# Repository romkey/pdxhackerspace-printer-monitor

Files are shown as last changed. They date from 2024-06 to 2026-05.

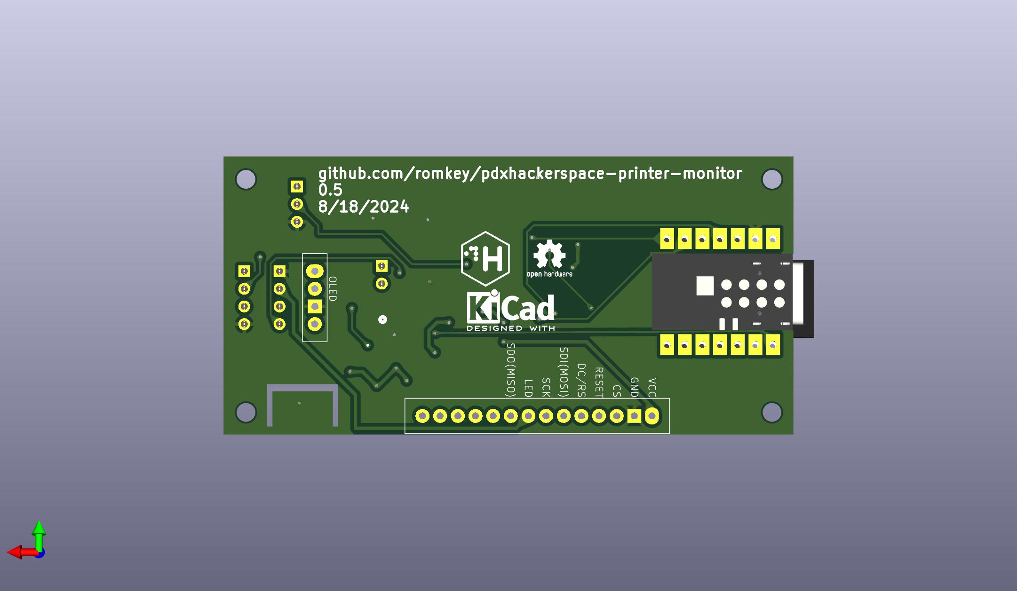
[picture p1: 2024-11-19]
hardware/0.5/back.jpg

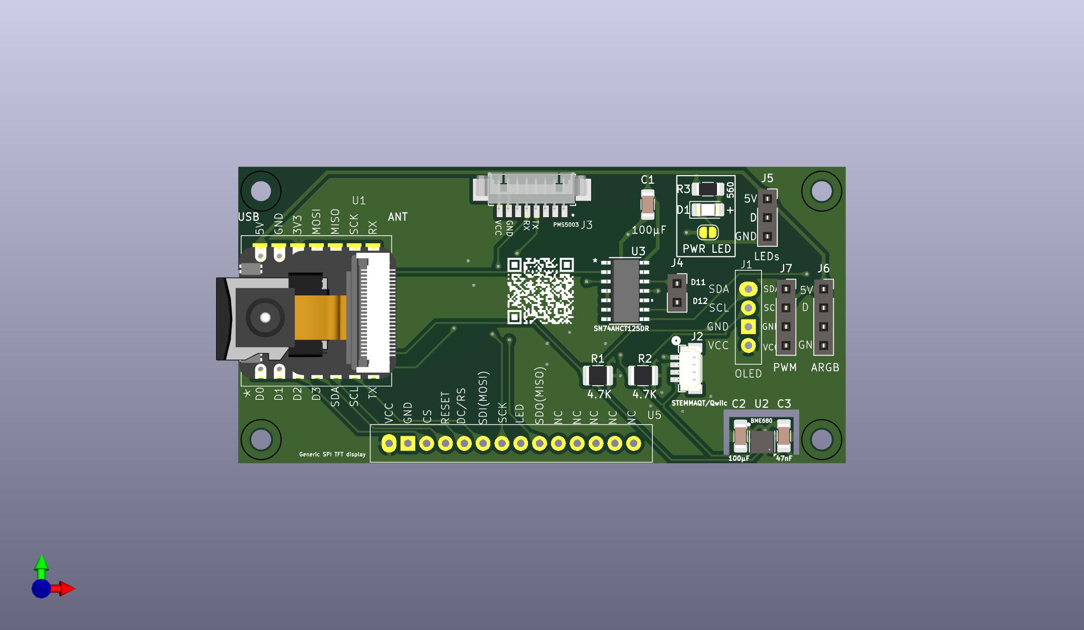
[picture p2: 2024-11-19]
hardware/0.5/front.jpg

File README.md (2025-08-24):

# PDX Hackerspace 3D Printer Monitor

This is a simple device for monitoring 3D printers.

It hosts a [SeeedStudio Xiao ESP32S3 Sense](https://www.seeedstudio.com/XIAO-ESP32S3-Sense-p-5639.html) CPU camera module so that its users can see the status of their prints.

It also can use a BME280 or BME680 for environmental (air temperature and humidity) monitoring, as well as a PMS5003 for air quality/particulate matter.

It includes an optional connection to an I2C display or a larger SPI-based RGB display, and can drive an addressable RGB LED strip for lighting.

## Modifying the Xiao S3 Sense

The Xiao S3 Sense has optional D11 and D12 pins. We can use these pins
to provide PWM signals to control an optional air filter fan, and to
run optional RGB LEDs on the fan. These signals are run through the
level shifter to bring them to 5V values.

Because we've run out of pins we need to use D11 and D12. By default
they're connected to the Xiao camera board's I2S microphone. The board
needs to be modified as documented
[here](https://wiki.seeedstudio.com/xiao_esp32s3_pin_multiplexing/#step-1-cut-off-the-connection-between-j1-and-j2).
Note that this web page incorrectly states the GPIO numbers for D11
and D12. D11 is actually GPIO42 and D12 is actually GPIO41.

## PCB

The PCB is designed using KiCAD. Hardware revisions are stored in the hardware directory.

You can [order this PCB from OSHPark](https://oshpark.com/shared_projects/bLoBvODi) but please don't order it. This project is under active albeit slow development. There will be a better version available soon.

PCB front PCB back 

## Software

The board is intended to integrate with Home Assistant. ESPHome is the easiest way to build code for it. The repo contains an example ESPHome definition file at esphome.yml, which needs its display functionality fleshed out.

## OV5640

https://github.com/0015/ESP32-OV5640-AF

## PrusaLink

Status observed:
- finished
- idle
- busy
- attention
- printing

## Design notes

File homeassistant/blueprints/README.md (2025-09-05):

# Prusa Printer Monitor Blueprint

A Home Assistant blueprint for monitoring Prusa printers and sending notifications to Slack with optional photo integration.

## Features

- **State Change Monitoring**: Automatically detects when your printer changes states (printing, paused, completed, failed, etc.)
- **Periodic Status Updates**: Sends status updates at configurable intervals (default: 15 minutes) while actively printing
- **Slack Integration**: Sends rich notifications to Slack with emojis and formatted messages
- **Photo Integration**: Optionally includes photos from ESPHome cameras in notifications
- **Temperature Monitoring**: Includes temperature data from ESPHome sensors (if available)
- **Spam Prevention**: Configurable timeout to prevent spam notifications when printer briefly becomes unavailable
- **Flexible Configuration**: Works with or without optional sensors/cameras

## Prerequisites

1. **PrusaLink Integration**: Your Prusa printer must be set up with the PrusaLink integration in Home Assistant
2. **Slack Integration**: The Slack integration must be configured in Home Assistant
3. **ESPHome Sensors** (Optional): If you have ESPHome-based sensors for temperature and camera

## Installation

1. Copy the `prusa_printer_monitor.yaml` file to your Home Assistant configuration directory
2. In Home Assistant, go to **Settings** → **Blueprints**
3. Click **Import Blueprint** and select the YAML file
4. Click **Use Blueprint** to create a new automation

## Configuration

### Required Inputs

- **Prusa Printer Entity**: Select your printer entity from the PrusaLink integration
- **Slack Notification Service**: Choose your Slack notification service (default: `notify.slack`)

### Optional Inputs

- **Camera Entity**: Select your ESPHome camera entity for photo attachments
- **Temperature Sensor**: Select your ESPHome temperature sensor entity
- **Status Update Interval**: How often to send status updates during printing (options: 5, 10, 15, 30, or 60 minutes; default: 15 minutes)
- **Enable Photo Attachments**: Toggle photo attachments on/off (default: true)

## Notification Types

### State Change Notifications

- **🖨️ Print Started**: When a new print job begins
- **✅ Print Completed**: When a print job finishes successfully
- **❌ Print Failed**: When a print job fails
- **⏸️ Print Paused**: When a print job is paused
- **▶️ Print Resumed**: When a paused print job resumes
- **🔄 Printer State Changed**: For any other state changes
- **🖨️ Printer Unavailable**: When printer is unavailable for extended period

### Periodic Updates

- **📊 Print Status Update**: Sent at configurable intervals (default: 15 minutes) while printing, including:
  - Current progress percentage
  - Time remaining
  - Print duration
  - Temperature (if sensor available)
  - Current photo (if camera available)

## Message Format

All notifications include:
- Printer name
- Current file being printed (if applicable)
- Progress percentage (if applicable)
- Timestamp
- Relevant status information
- Optional photo attachment

## Example Notifications

### Print Started
```
🖨️ Print Started

A new print job has started!

**Printer:** Prusa i3 MK3S+
**File:** calibration_cube.gcode
**Progress:** 0%
**Time:** 2024-01-15 14:30:25
```

### Status Update
```
📊 Print Status Update

**Printer:** Prusa i3 MK3S+
**File:** calibration_cube.gcode
**Progress:** 45%
**Time Remaining:** 1h 23m
**Print Duration:** 2h 15m
**Temperature:** 23.5°C
**Time:** 2024-01-15 16:45:30
```

### Print Completed
```
✅ Print Completed

Print job completed successfully!

**Printer:** Prusa i3 MK3S+
**File:** calibration_cube.gcode
**Duration:** 4h 32m
**Time:** 2024-01-15 19:02:45
```

## Troubleshooting

### Printer Shows as Unavailable
- Check your PrusaLink connection
- Verify the printer is powered on and connected to the network
- The blueprint includes a configurable timeout to prevent spam notifications

### Photos Not Appearing
- Ensure your camera entity is properly configured
- Check that the camera has an `entity_picture` attribute
- Verify the `enable_photos` option is set to true

### Temperature Not Showing
- Make sure your temperature sensor entity is selected
- Verify the sensor is reporting valid temperature values

### Slack Notifications Not Working
- Check your Slack integration configuration
- Verify the notification service name is correct
- Test the notification service manually

## Customization

You can modify the blueprint to:
- Add additional notification channels (Discord, Telegram, etc.)
- Include more sensor data (humidity, air quality, etc.)
- Change notification frequency
- Add custom message formatting
- Include additional printer attributes

## Support

For issues or questions:
1. Check the Home Assistant logs for error messages
2. Verify all entity names and service names are correct
3. Test individual components manually before using the blueprint

## License

This blueprint is provided as-is for educational and personal use.

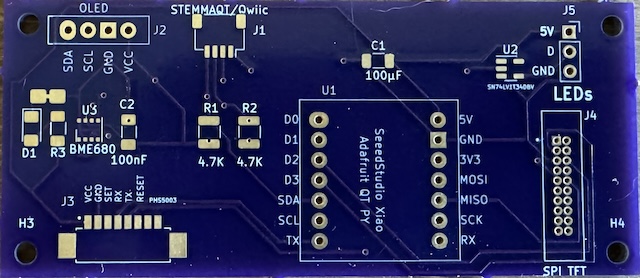
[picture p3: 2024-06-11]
images/0.02-front.jpg

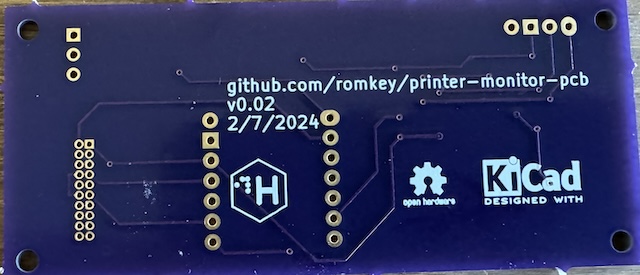
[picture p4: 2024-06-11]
images/0.02-back.jpg

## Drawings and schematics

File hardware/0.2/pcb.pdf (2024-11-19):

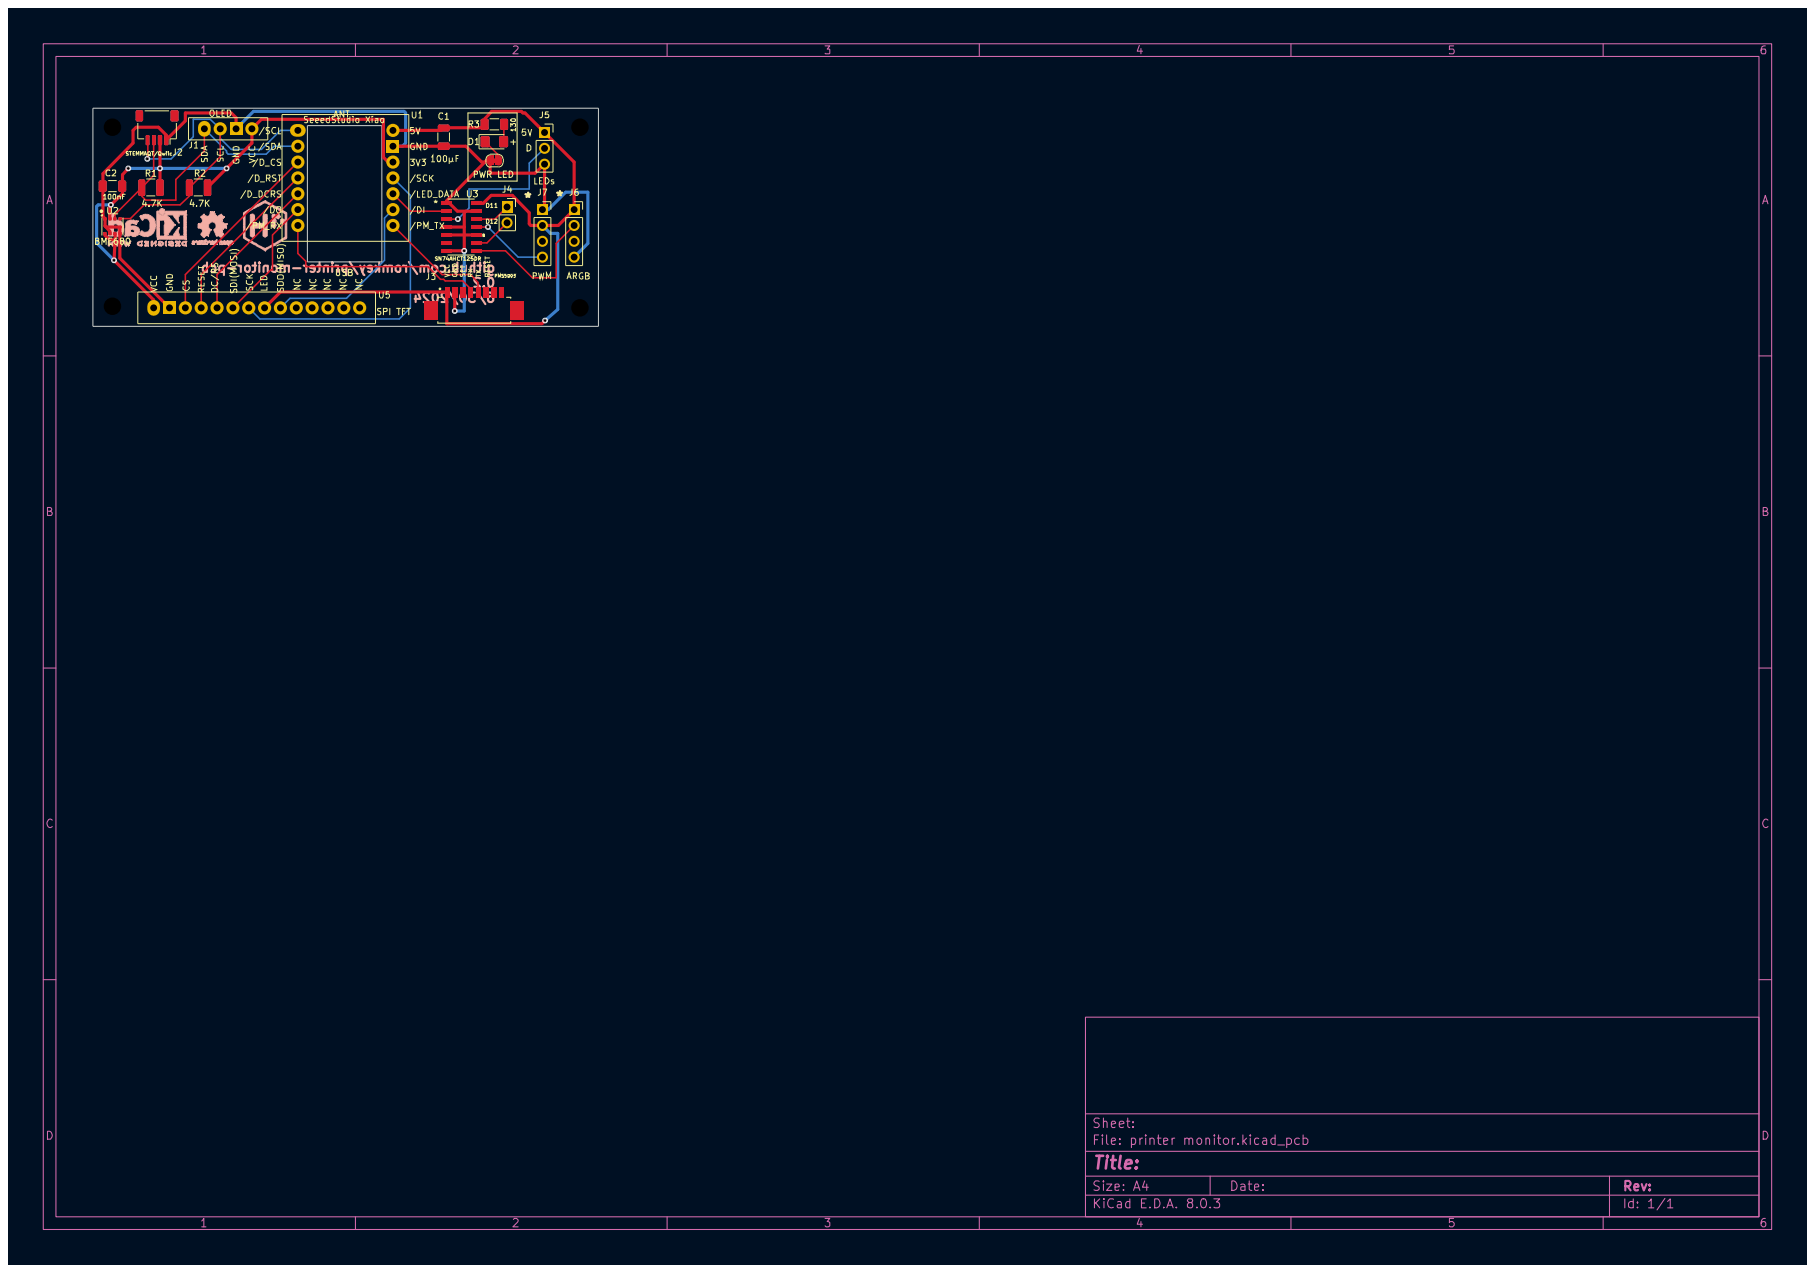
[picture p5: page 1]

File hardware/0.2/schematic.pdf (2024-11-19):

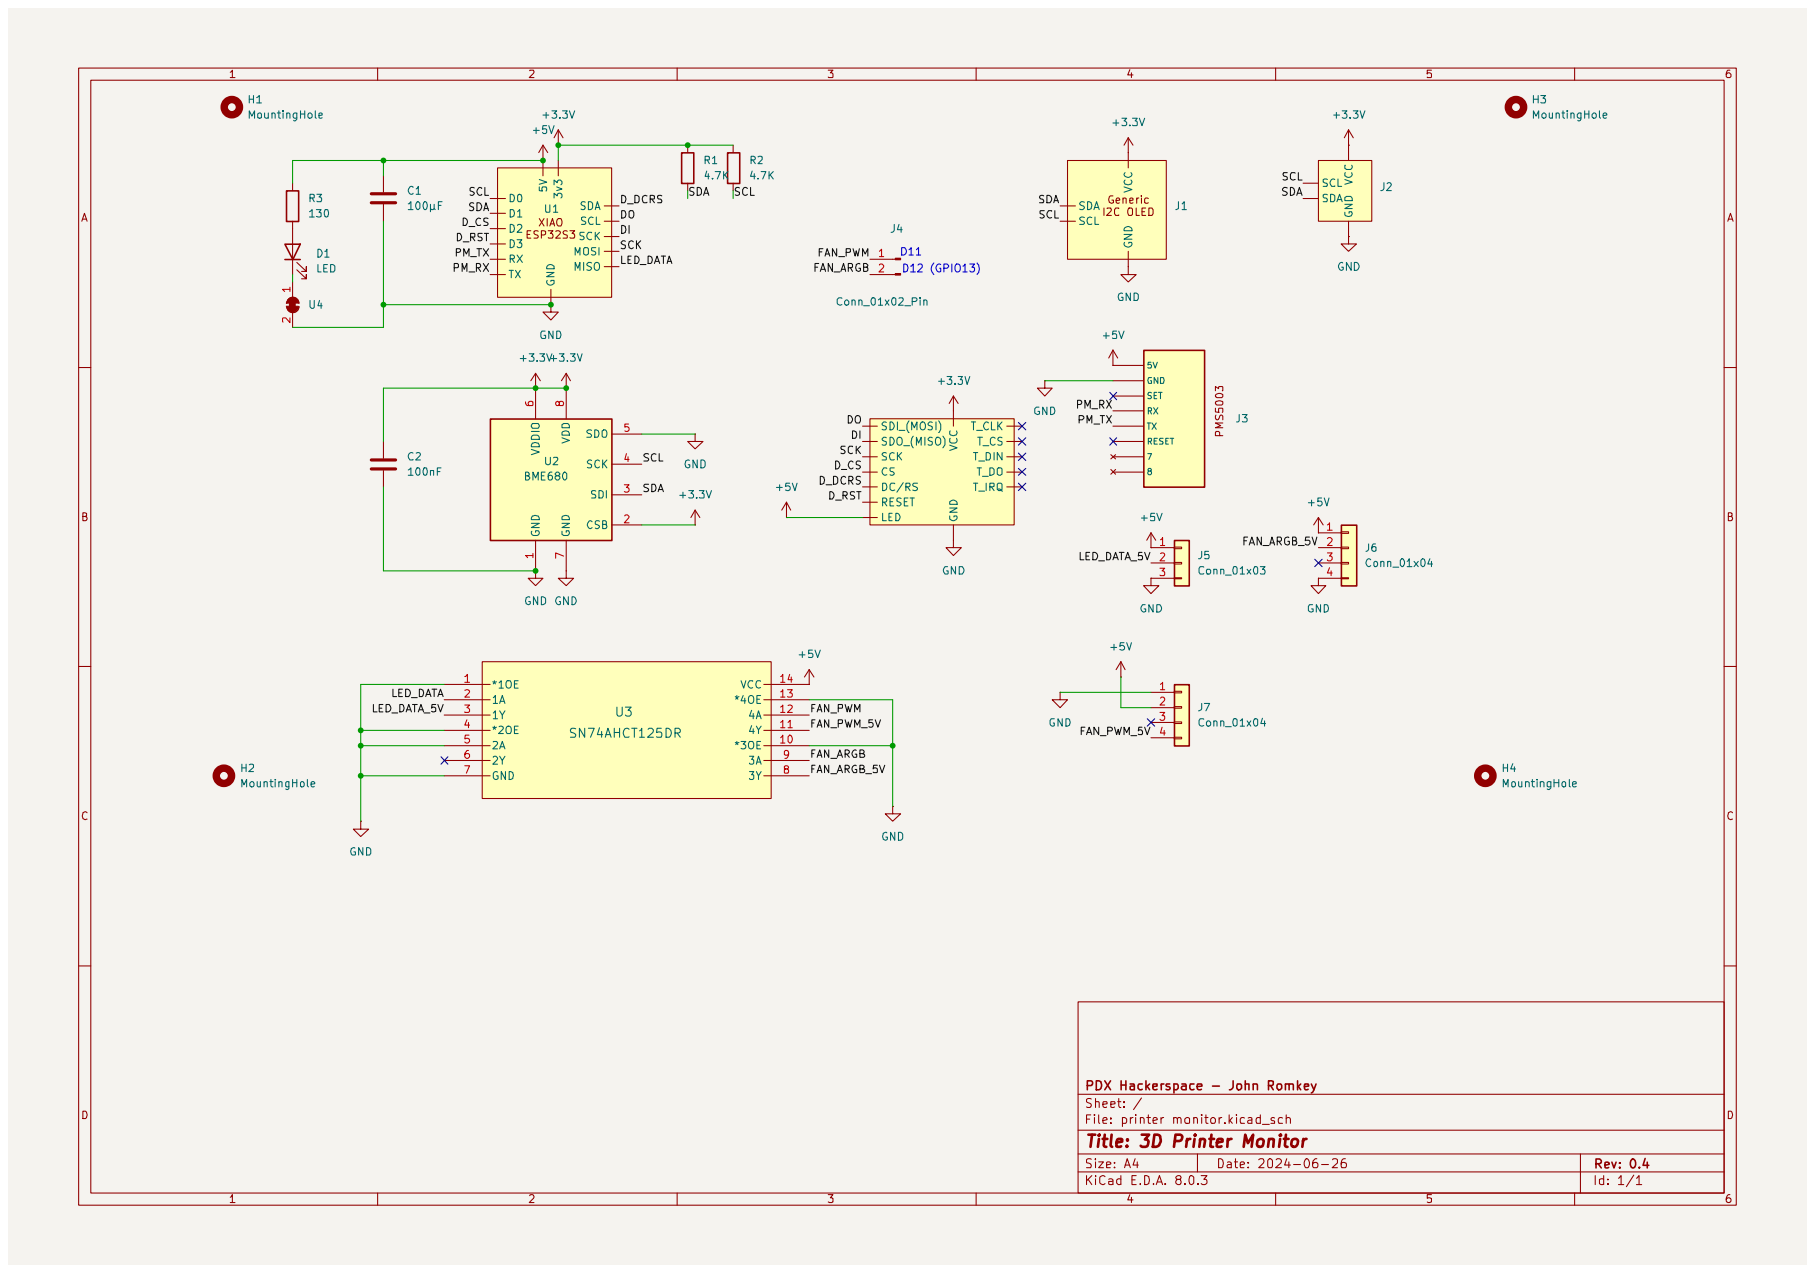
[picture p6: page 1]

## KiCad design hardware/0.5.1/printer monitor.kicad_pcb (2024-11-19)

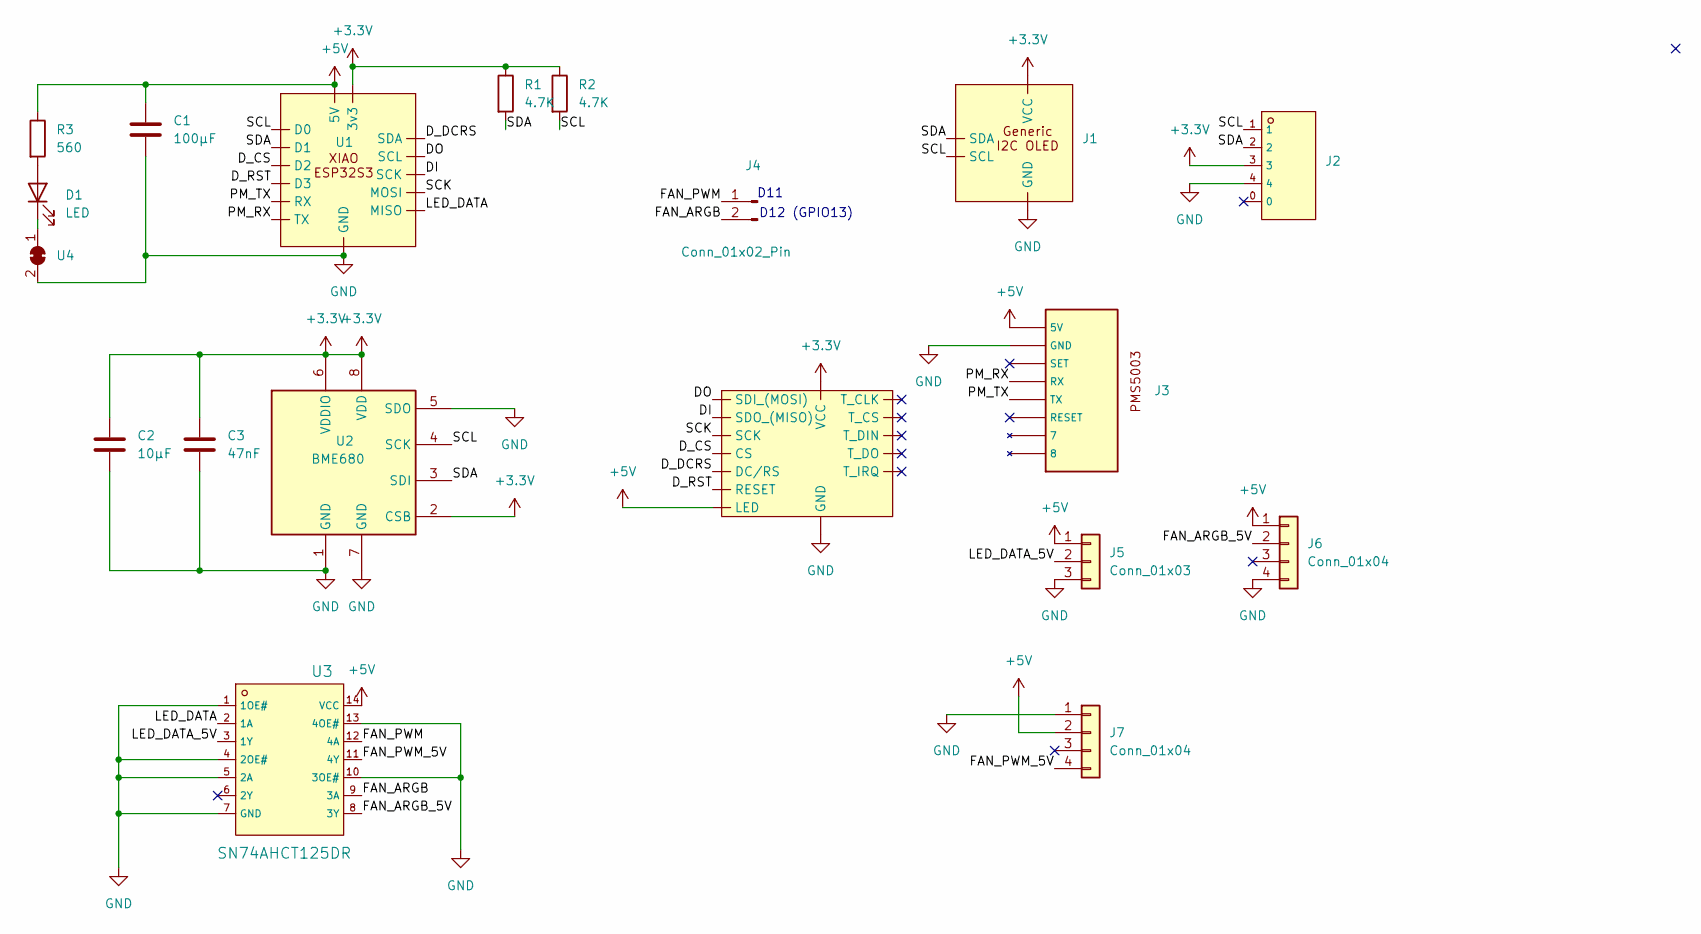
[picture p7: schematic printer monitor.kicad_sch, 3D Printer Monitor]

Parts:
C1: 100µF; CP_Elec_6.3x5.7; MPN C5155334
C2: 10µF; C_0805_2012Metric_Pad1.18x1.45mm_HandSolder; MPN C342724
C3: 47nF; C_0603_1608Metric_Pad1.08x0.95mm_HandSolder; MPN C123512
D1: LED; LED_1206_3216Metric_Pad1.42x1.75mm_HandSolder; MPN C375482
J1: Generic I2C OLED
J2: CONN-SMD_BM04B-SRSS-TB; MPN C160390; LCSC C160390
J3: PMS5003 Connector
J4: Conn_01x02_Pin; PinSocket_1x02_P2.54mm_Vertical
J5: Conn_01x03; PinSocket_1x03_P2.54mm_Vertical
J6, J7: Conn_01x04; PinSocket_1x04_P2.54mm_Vertical
R1, R2: 4.7K; R_0805_2012Metric_Pad1.20x1.40mm_HandSolder; MPN C105427
R3: 560; R_1206_3216Metric_Pad1.30x1.75mm_HandSolder; MPN С319525
U1: Xiao ESP32S3 Sense (Camera)
U2: BME680; Bosch_LGA-8_3x3mm_P0.8mm_ClockwisePinNumbering; MPN C125972
U3: SN74AHCT125DR; SOIC-14_L8.7-W3.9-P1.27-LS6.0-BL; MPN C155176; LCSC C155176
U4: SolderJumper-2_P1.3mm_Bridged_RoundedPad1.0x1.5mm
U5: SPI_TFT_TOUCH

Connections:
+3.3V: C2.1, C3.1, J1.4 (VCC), J2.3, R1.1, R2.1, U1.12 (3v3), U2.2 (CSB), U2.6 (VDDIO), U2.8 (VDD), U5.1 (VCC)
+5V: C1.1, J3.1 (5V), J5.1, J6.1, J7.2, R3.1, U1.14 (5V), U3.14 (VCC), U5.8 (LED)
/DI: U1.9 (SCK), U5.9 (SDO_(MISO))
/DO: U1.6 (SCL), U5.6 (SDI_(MOSI))
/D_CS: U1.3 (D2), U5.3 (CS)
/D_DCRS: U1.5 (SDA), U5.5 (DC/RS)
/D_RST: U1.4 (D3), U5.4 (RESET)
/FAN_ARGB: J4.2, U3.9 (3A)
/FAN_ARGB_5V: J6.2, U3.8 (3Y)
/FAN_PWM: J4.1, U3.12 (4A)
/FAN_PWM_5V: J7.4, U3.11 (4Y)
/LED_DATA: U1.10 (MISO), U3.2 (1A)
/LED_DATA_5V: J5.2, U3.3 (1Y)
/PM_RX: J3.4 (RX), U1.7 (TX)
/PM_TX: J3.5 (TX), U1.8 (RX)
/SCK: U1.11 (MOSI), U5.7 (SCK)
/SCL: J1.2 (SCL), J2.1, R2.2, U1.1 (D0), U2.4 (SCK)
/SDA: J1.1 (SDA), J2.2, R1.2, U1.2 (D1), U2.3 (SDI)
GND: C1.2, C2.2, C3.2, J1.3 (GND), J2.4, J3.2 (GND), J5.3, J6.4, J7.1, U1.13 (GND), U2.1 (GND), U2.5 (SDO), U2.7 (GND), U3.1 (1OE#), U3.4 (2OE#), U3.5 (2A), U3.7 (GND), U3.10 (3OE#), U3.13 (4OE#), U4.2 (B), U5.2 (GND)
unnamed: D1.2 (A), R3.2
unnamed: D1.1 (K), U4.1 (A)

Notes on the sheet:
D11
D12 (GPIO13)

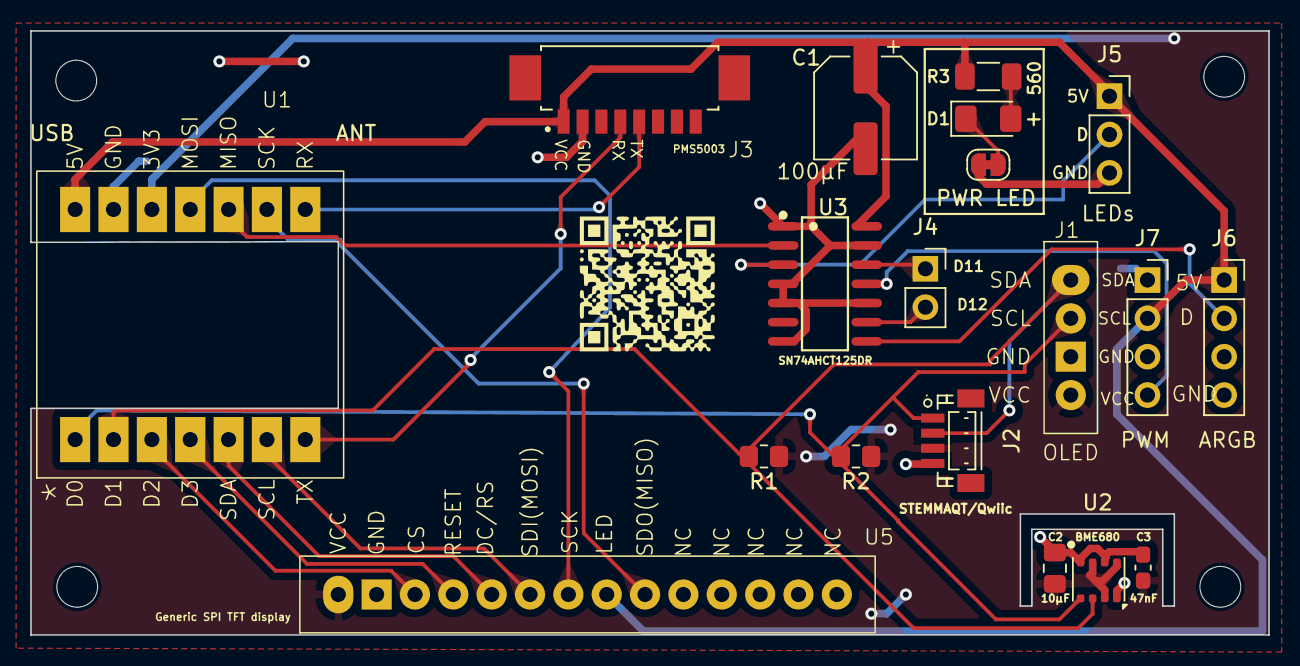
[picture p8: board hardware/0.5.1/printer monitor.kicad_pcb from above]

Board: 2 copper layers, 82.0 x 40.0 mm, 23 parts (0 on the bottom side), 21 nets.

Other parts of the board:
H1, H2, H3, H4: MountingHole; MountingHole_2.7mm_M2.5

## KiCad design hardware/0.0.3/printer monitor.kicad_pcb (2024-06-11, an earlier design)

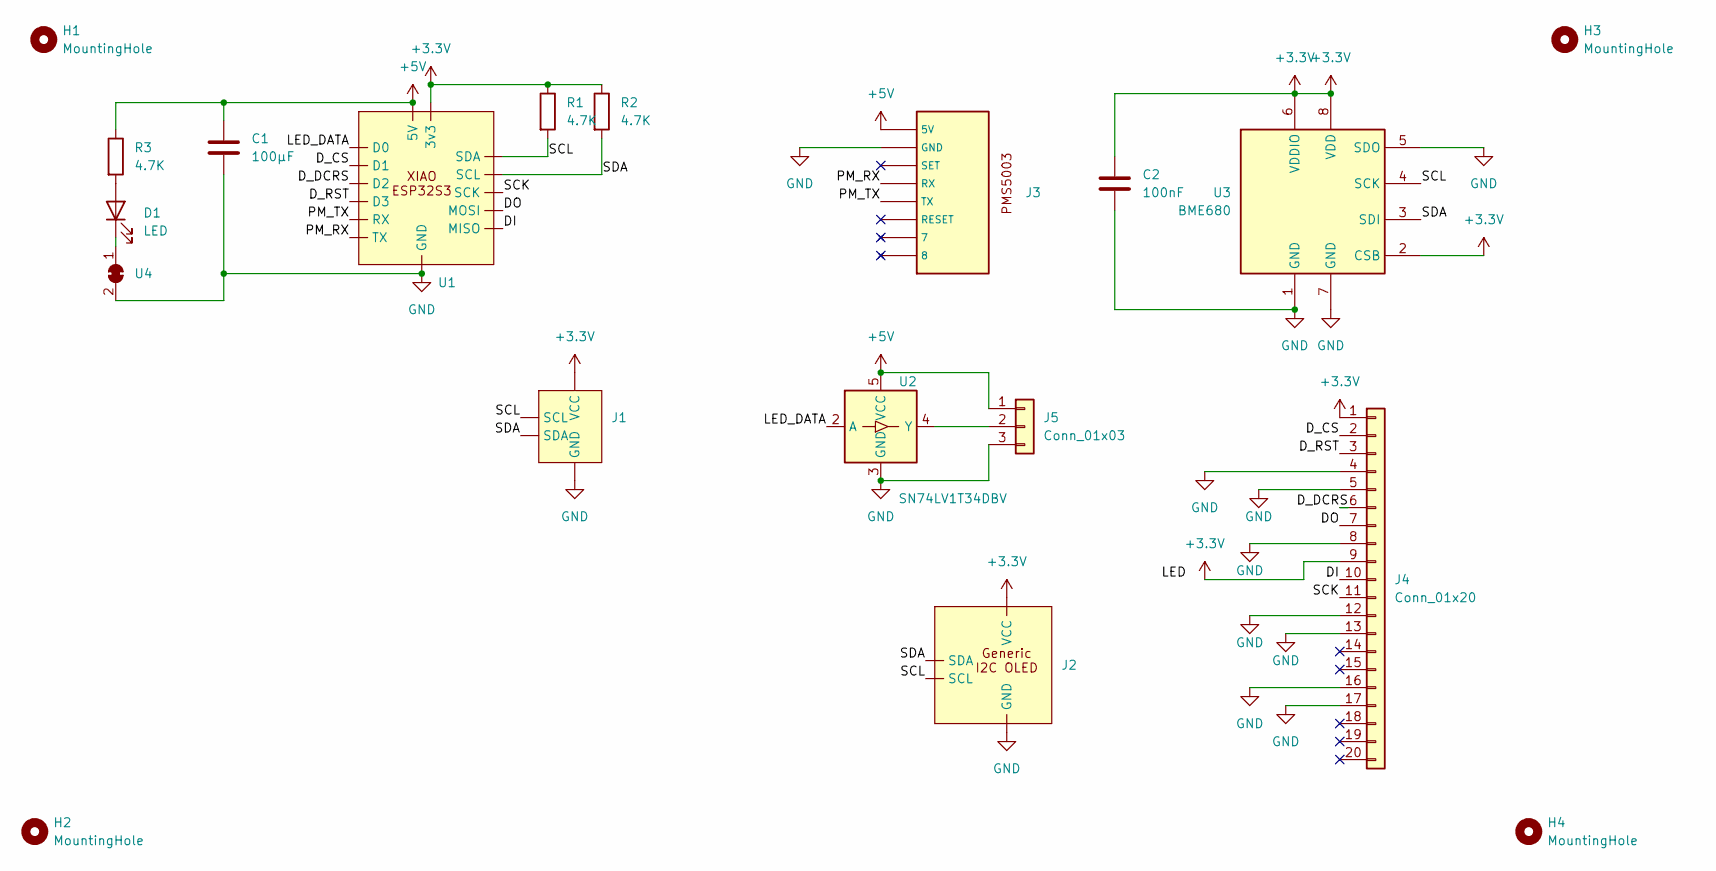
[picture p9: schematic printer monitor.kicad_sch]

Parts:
C1: 100µF; C_1206_3216Metric
C2: 100nF; C_1206_3216Metric_Pad1.33x1.80mm_HandSolder
D1: LED; LED_1206_3216Metric_Pad1.42x1.75mm_HandSolder
H1, H2, H3, H4: MountingHole; MountingHole_2.7mm_M2.5
J1: JST_SH_SM04B-SRSS-TB_1x04-1MP_P1.00mm_Horizontal
J2: Generic I2C OLED
J3: PMS5003 Connector
J4: Conn_01x20; AMPHENOL_20021511-00020T4LF
J5: Conn_01x03; PinSocket_1x03_P2.54mm_Vertical
R1, R2: 4.7K; R_1210_3225Metric
R3: 4.7K; R_1206_3216Metric_Pad1.30x1.75mm_HandSolder
U1: Xiao ESP32S3
U2: SN74LV1T34DBV; SOT-23-5
U3: BME680; Bosch_LGA-8_3x3mm_P0.8mm_ClockwisePinNumbering
U4: SolderJumper-2_P1.3mm_Bridged_RoundedPad1.0x1.5mm

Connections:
+3.3V: C2.1, J1.2 (VCC), J2.4 (VCC), J4.1, J4.9, R1.1, R2.1, U1.12 (3v3), U3.2 (CSB), U3.6 (VDDIO), U3.8 (VDD)
+5V: C1.1, J3.1 (5V), J5.1, R3.1, U1.14 (5V), U2.5 (VCC)
/DI: J4.10, U1.10 (MISO)
/DO: J4.7, U1.11 (MOSI)
/D_CS: J4.2, U1.2 (D1)
/D_DCRS: J4.6, U1.3 (D2)
/D_RST: J4.3, U1.4 (D3)
/LED_DATA: U1.1 (D0), U2.2 (A)
/PM_RX: J3.4 (RX), U1.7 (TX)
/PM_TX: J3.5 (TX), U1.8 (RX)
/SCK: J4.11, U1.9 (SCK)
/SCL: J1.4 (SCL), J2.2 (SCL), R1.2, U1.5 (SDA), U3.4 (SCK)
/SDA: J1.3 (SDA), J2.1 (SDA), R2.2, U1.6 (SCL), U3.3 (SDI)
GND: C1.2, C2.2, J1.1 (GND), J2.3 (GND), J3.2 (GND), J4.4, J4.5, J4.8, J4.12, J4.13, J4.16, J4.17, J5.3, U1.13 (GND), U2.3 (GND), U3.1 (GND), U3.5 (SDO), U3.7 (GND), U4.2 (B)
unnamed: D1.2 (A), R3.2
unnamed: D1.1 (K), U4.1 (A)
unnamed: J5.2, U2.4 (Y)

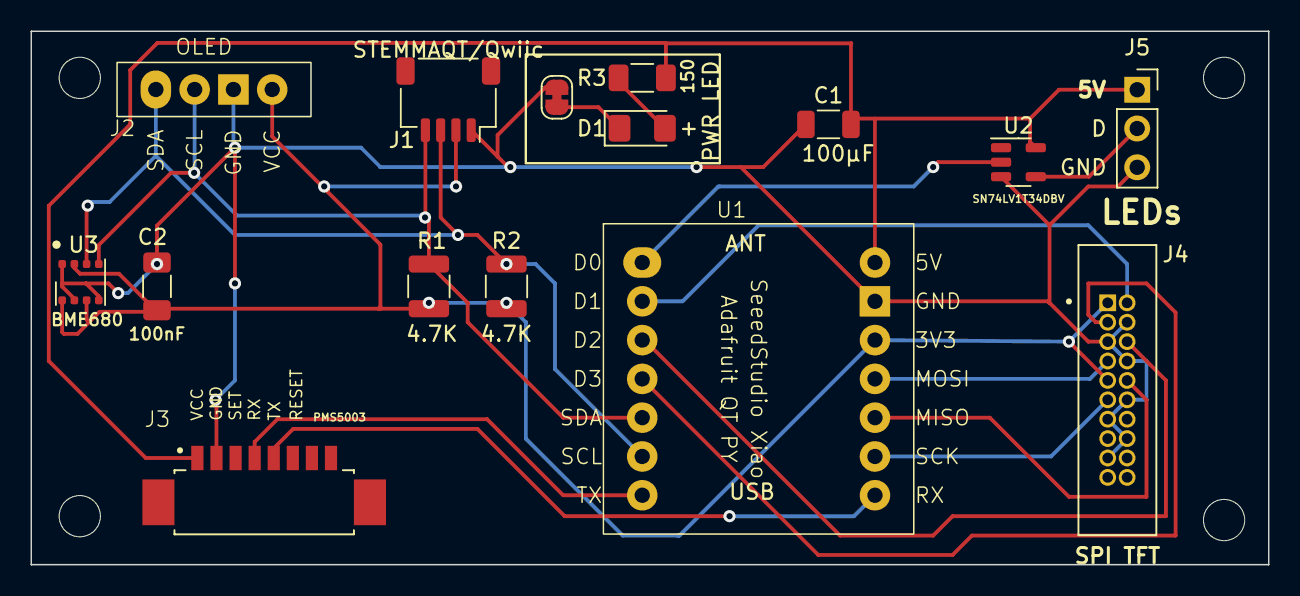
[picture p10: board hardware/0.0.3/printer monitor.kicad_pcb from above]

Board: 2 copper layers, 81.0 x 34.9 mm, 19 parts (0 on the bottom side), 17 nets.

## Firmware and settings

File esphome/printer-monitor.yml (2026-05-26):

esphome:
  project:
    name: "pdxhackerspace.printer_monitor"
    version: "0.4.0"
  on_boot:
    priority: 500
    then:
      - light.turn_on:
          id: leds
          red: 100%
          green: 100%
          blue: 100%
  on_shutdown:
    priority: 500
    then:
      - light.turn_off: leds

# D11 is GPIO42
# D12 is GPIO41
# For info on how to use them see https://wiki.seeedstudio.com/xiao_esp32s3_pin_multiplexing/#for-sense-version

packages:
  wifi-diagnostics: github://romkey/esphome-lib/lib/wifi-diagnostics.yml@main
  esp32-diagnostics: github://romkey/esphome-lib/lib/esp32.yml@main

logger:

api:
  id: hass

ota:
  platform: esphome

wifi:
  id: wifi_id

time:
  - platform: homeassistant
    id: homeassistant_time
    timezone: ${timezone}

web_server:
  port: 80
  version: 3

font:
  - file: 'fonts/FantasqueSansMono-Regular.ttf'
    id: font_small
    size: 20
  - file: 'fonts/FantasqueSansMono-Regular.ttf'
    id: font_medium
    size: 50
  - file: 'fonts/FantasqueSansMono-Regular.ttf'
    id: font_large
    size: 80
  - file: 'fonts/FantasqueSansMono-Regular.ttf'
    id: font_xlarge
    size: 140
  - file: 'fonts/FantasqueSansMono-Regular.ttf'
    id: font_xxlarge
    size: 180
# https://community.home-assistant.io/t/az-touch-esp-example/383573/22
  - file: 'fonts/MaterialIcons-Regular.ttf'
    id: font_icons
    size: 22
    glyphs:
#      - "\U000F0590" # cloudy
#      - "\U000F0595" # partlycloudy
#      - "\U000F0591" # fog      
#      - "\U000F0592" # hail
#      - "\U000F067E" # lightning-rainy
#      - "\U000F0596" # pouring
#      - "\U000F0597" # rainy
#      - "\U000F0F36" # snowy
#      - "\U000F067F" # snowy-rainy
#      - "\U000F0599" # sunny
#      - "\U000F0F33" # light-rain
#      - "\U000F0F34" # flurries
#      - "\U000F0598" # light-snow
#      - "\U000F0F35" # freezing-drizzle
#      - "\U000F0502" # television off
#      - "\U000F0594" # star night
#      - "\U000F1A4C" # night light
#      - "\U000F1051" # led strip on
#      - "\U000F18DD" # multiple ceiling lights filled
#      - "\U000F0335" # light bulb filled
#      - "\U000F0336" # light bulb outline
#      - "\U000F12CF" # multiple lights off
#      - "\U000F18DE" # multiple ceiling lights outline
#      - "\U000F1253" # multiple bulbs filled
#      - "\U000F1254" # multiple bulbs outline
#      - "\U000F1A4B" # led strip off
#      - "\U000F0503" # television on
#      - "\U000F0395" # dashboard
      - "\U0000E63E" # wifi
      - "\U0000E648" # no-wifi
  - file: 'fonts/MaterialIcons-Regular.ttf'
    id: font_icons_small
    size: 20
    glyphs:
      - "\U0000E63E" # wifi
      - "\U0000E648" # no-wifi
  - file: 'fonts/MaterialIcons-Regular.ttf'
    id: font_icons_120pt
    size: 120
    glyphs:
      - "\U0000E5CA" # check
      - "\U0000E63E" # wifi
      - "\U0000E648" # no-wifi
  - file: 'fonts/MaterialIcons-Regular.ttf'
    id: font_icons_200pt
    size: 200
    glyphs:
      - "\U0000E63E" # wifi
      - "\U0000E648" # no-wifi

color:
  - id: my_red
    red: 100%
    green: 0%
    blue: 0%
  - id: my_green
    red: 0%
    green: 100%
    blue: 0%
  - id: my_white
    red: 100%
    green: 100%
    blue: 100%

esp32_camera:
  name: My Camera
  external_clock:
    pin: GPIO10
    frequency: 20MHz
  i2c_id: i2c_camera
  data_pins: [GPIO15, GPIO17, GPIO18, GPIO16, GPIO14, GPIO12, GPIO11, GPIO48]
  vsync_pin: GPIO38
  href_pin: GPIO47
  pixel_clock_pin: GPIO13
  resolution: ${camera_resolution}
  jpeg_quality: ${camera_jpeg_quality}
  vertical_flip: ${camera_vertical_flip}
  horizontal_mirror: ${camera_horizontal_mirror}

esp32_camera_web_server:
  - port: 8080
    mode: stream
  - port: 8081
    mode: snapshot

i2c:
  - id: i2c0
    sda: 2
    scl: 1
  - id: i2c_camera
    sda: GPIO40
    scl: GPIO39

spi:
  miso_pin: GPIO7
  mosi_pin: GPIO6
  clk_pin: GPIO9

uart:
  id: serial0
  tx_pin: GPIO43
  rx_pin: GPIO44
  baud_rate: 9600  

sensor:
  - platform: pmsx003
    type: PMSX003
    uart_id: serial0
    pm_1_0:
      name: "Particulate Matter <1.0µm Concentration"
    pm_2_5:
      name: "Particulate Matter <2.5µm Concentration"
    pm_10_0:
      name: "Particulate Matter <10.0µm Concentration"  

  - platform: bme680
    temperature:
      name: "BME680 Temperature"
      oversampling: 16x
      filters:
        - offset: ${bme_temperature_offset}      
    pressure:
      name: "BME680 Pressure"
    humidity:
      name: "BME680 Humidity"
    gas_resistance:
      name: "BME680 Gas Resistance"
    address: 0x76
    update_interval: 60s
    i2c_id: i2c0

  - platform: homeassistant
    name: "Canonical Temperature"
    id: canonical_temperature
    entity_id: sensor.openweathermap_temperature
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

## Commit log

2024-07-01 updated esphome.yml
    new rev of board with PWM and ARGB fan support
    centered camera
    expanded SPI-TFT display header
    [printer monitor.kicad_pcb, printer monitor.kicad_sch]
2024-11-19 updated ESPHome definitions to work with substitutions and be includable from github
    updated KiCAD files for PCB
    [printer monitor.kicad_pcb, printer monitor.kicad_sch]
2024-12-28 Update printer-monitor.yml
    restored some optional values, reduced SPI speed
2025-05-03 Try to fix remaining time
    [printer-monitor.yml]
2025-05-03 Attempt to fix time remaining on long prints
    [printer-monitor.yml]
2025-08-04 Fix & improve printer display when printing
    [printer-monitor.yml]
2025-08-09 camera I2C fix
    change camera definition to use defined I2C controller, i2c_pins is gone
    [printer-monitor.yml]
2025-08-10 Update printer-monitor.yml
    fixed comments in C++ code
    [printer-monitor.yml]
2025-08-10 Update printer-monitor.yml
    Try to fix a % problem, needs ints
    [printer-monitor.yml]
2025-08-24 README changes
    new printer monitor blueprint for testing
2025-08-25 Fix some text going offscreen and handle quirks with time remaining values
    [printer-monitor.yml]
2025-09-05 lots of updates to printer monitor blueprint - new control for posting interval - fixed many errors - delineators around messages
2026-05-26 Add web server configuration to printer-monitor.yml
    Added web server configuration with port and version. Get rid of deprecated LED effect addressable_rainbow
2026-05-26 Remove Rainbow effect from printer monitor config
